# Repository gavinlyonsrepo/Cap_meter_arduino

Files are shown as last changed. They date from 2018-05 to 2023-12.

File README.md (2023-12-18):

    

# Table of contents

  * [Table of contents](#table-of-contents)
  * [Overview](#overview)
  * [Libraries](#libraries)
  * [Parts list](#parts-list)
  * [Software](#software)
	* [Test 1](#test-1)
	* [Test 2](#test-2)
	* [Test 3](#test-3)
  * [Project Schematic](#project-schematic)
  * [See  Also](#see-also)
  
## Overview

* Name : Cap_meter_arduino
* Title : Capacitance meter Arduino based microcontroller.
* Description : Capacitance meter for Arduino, three tests , 
range 18pf to 4F , Push Button input , OLED, serial monitor output and LED(onboard NANO)
* Author: Gavin Lyons

## Libraries

The .ino file( which contains the C++ source code) calls from a number of libraries.

All are standard libraries which can be found on Arduino libray manager.
 
* <Adafruit_SSD1306.h> v 1.1.2 // OLED
* <Button.h> v 1.0.0 // pb https://www.arduinolibraries.info/authors/madleech or https://github.com/madleech/Button

## Parts List

Eagle schematic diagram and image in "docs". 

You will need following parts

> Three pushbuttons
>
> Resistors: Test2( 10K and 220ohm) , Test3(10K, 3.1K, 1.8K)
>
> Arduino NANO micro-controller module (tested on a NANO and UNO)
>
> I2C 0.91" inch 128x32 OLED Display Module SSD1306 Driver IC
>
> Terminals to hold or connect to capacitors during test
>

## Software

The meter measures capacitance it outputs to an OLED and serial monitor.
(The OLED is optional as data via serial monitor on a PC)
Three push buttons start the three tests respectively.

1. Test 1 Range  1 uF to 4F.
2. Test 2 Range 18 pF to 470 uF.
3. Test 3 Range 4.7 nF to 180 uF.

The on-board LED of nano module D13 is used as Status LED.
It Flashes during startup, stays on during "READY to test" state and goes off during "TESTING" state

The OLED displays  brief help message and title screen duirng start-up

Each Arduino capacitance meter relies on a property of resistor capacitor (RC) circuits- the time constant. 
The time constant of an RC circuit is defined as the time it takes for the voltage across the capacitor 
to reach 63.2% of its voltage when fully charged:

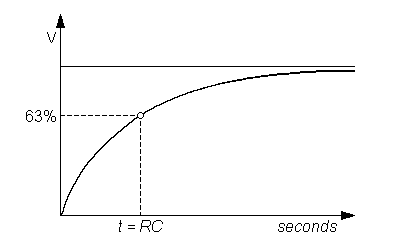
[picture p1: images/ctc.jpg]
ScreenShot cap time constant


Larger capacitors take longer to charge, and therefore will create larger time constants. 
The capacitance in an RC circuit is related to the time constant by the equation:

ScreenShot cap eq constant

The capacitance meter has an RC circuit with known resistor values and an unknown capacitor value. 
The Arduino will measure the voltage at the capacitor and record the time it takes to reach 63.2% of it’s voltage when fully charged (the time constant). 
Since the resistance value is already known, 
we can use the formula above in a program that will calculate the unknown capacitance.

### Test 1

Test 1: Range  1 uF to 4F. 
Uses two digital pins, one analog pin, and two resistors.
One for discharge, one for charge.
Insert a capacitor in range into terminal press button and view result on OLED or serial monitor.
The Capacitor is charged,  We can measure elapsed time until time constant fulfilled using analog pin and we know R 
value. Therefore we solve for C. 
The result gives two values: Capacitance value and time constant to test in mS.
The user can adjust the 10K resistor value in code variable(resistorValue) to match exact value, to improve accuracy

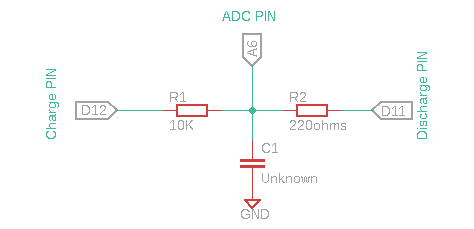
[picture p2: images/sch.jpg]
ScreenShot cap sch


### Test 2

Test 2 : Range 18 pF to 470 uF.

This capacitance test has the greatest range of 3. It also had the highest accuracy with smaller capacitors. 
No resistors are needed and it only uses two analog pins(A2(neg) and A3(positive) from the Arduino.
There is no extra resistor just the internal components of ATmega328 chip.

C1 calibration(optional): 

The internal analog pin capacitor to gnd (C1) varies between 20 and 30pF. unknown capacitor = Cu. The positive pin is set to 5V, the negative to 0V.

VA2 = (VA3 * Cu)/(C1 + Cu)

The value of C1 for any given Arduino board will have to be calibrated using a known cap for Cu,
for full accuracy I set it at 24.48pF in code (CapOne) Found using equation.

C1 = Cu * (VA3-VA2) / VA2

Where  Va2 is ADC value reported by code and VA3 is 5v or 1023.
So for a known capacitor of 103pF giving a ADC value of 801.

C1 = 103pf * (1023-801)/ 801 = 28.48pF.

The user should change this for their system to improve accuracy.
Test a known cap get ADC value and then pop these values into equation above
and put the C1 value into (CapOne) variable in code.

Test equation:

Cu = VA2 * C1 / (VA3 - VA2)

The test displays 3 values 
* Cu,  Capacitance in Farads 
* Time constant for test in mS
* Va2 , ADC measurement from 0 to 1023 where 1023 is 5V 

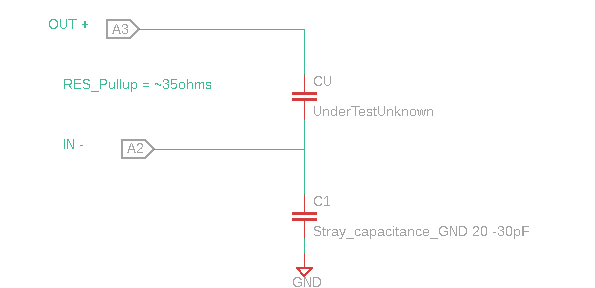
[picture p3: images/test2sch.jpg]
ScreenShot cap sch 2


### Test 3

Test 3 Range 0.0047 uF to 180 uF.

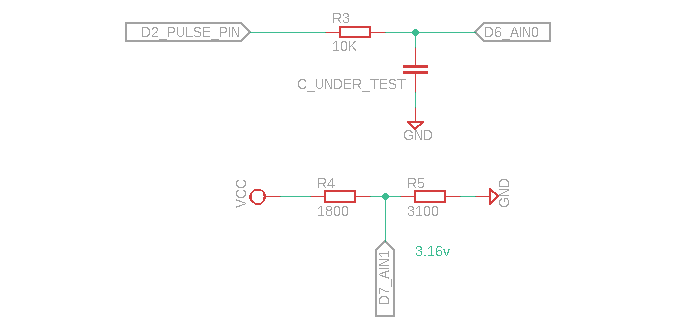
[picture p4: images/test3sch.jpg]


A voltage divider is created to give a reference voltage,

Vout = Vin * (R5 / (R5 + R4)) , 5 * (3100 / (1800 + 3100)) = 3.163.

The objective here is to find the time constant τ (tau) in the equation:

τ = R * C Solved for C: C = τ / R

So we want to charge the capacitor under test with a suitable voltage (eg. 5V from an Arduino output pin) and measure how long it takes to reach 63.2% of that voltage. So we need a reference voltage of 5 * 0.632, namely 3.16V.
The internal analogue comparator is used for this job.:

1. pin 6 PD6 AIN0
2. pin 7 PD7 AIN1
 
We connect the reference voltage to the AIN1 pin (negative reference) and connect our capacitor to the AIN0 pin (positive reference) and then configure an interrupt on the rising edge. A value of 10K for the resistor to give a reasonably slow charge time. The value of ~ 10K is specified in code variable (resistance).
so adjust for your resistor value , I have 9830 ohms. Make sure to pick accurate resistors for voltage divider.

The test returns the Capacitance result and time constant.

## Project Schematic 

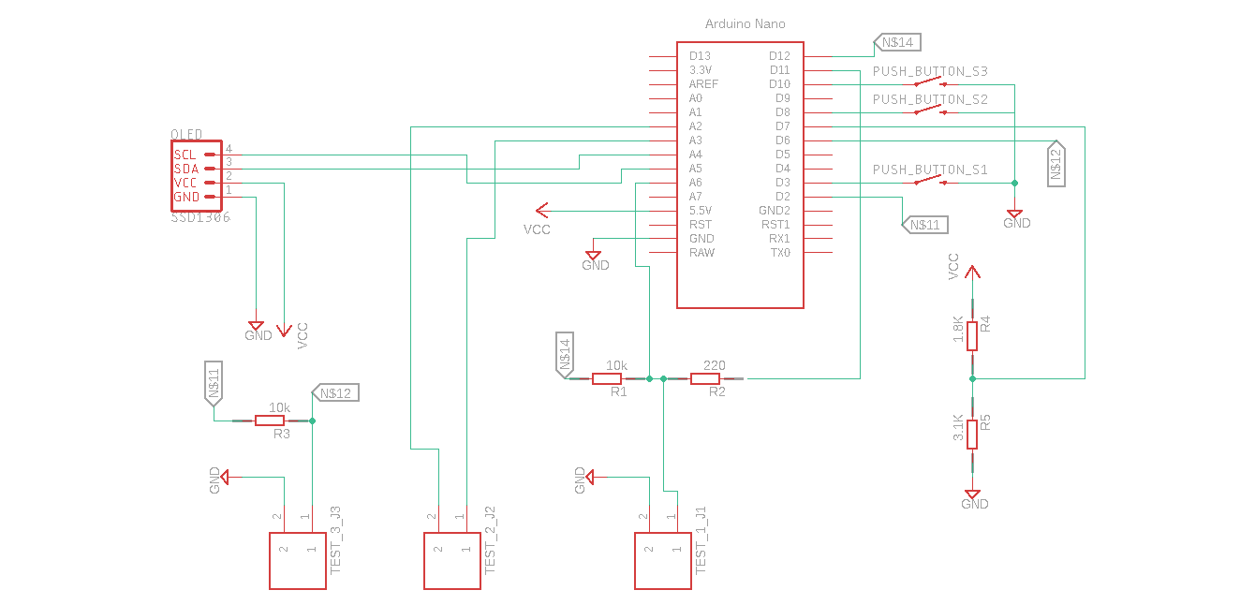
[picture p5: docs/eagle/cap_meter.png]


## See Also
 
* https://www.arduino.cc/en/Tutorial/CapacitanceMeter
* http://www.circuitbasics.com/how-to-make-an-arduino-capacitance-meter/
* http://electronoobs.com/eng_arduino_tut10_1.php
* http://wordpress.codewrite.co.uk/pic/2014/01/21/cap-meter-with-arduino-uno/
* http://www.gammon.com.au/forum/?id=12075

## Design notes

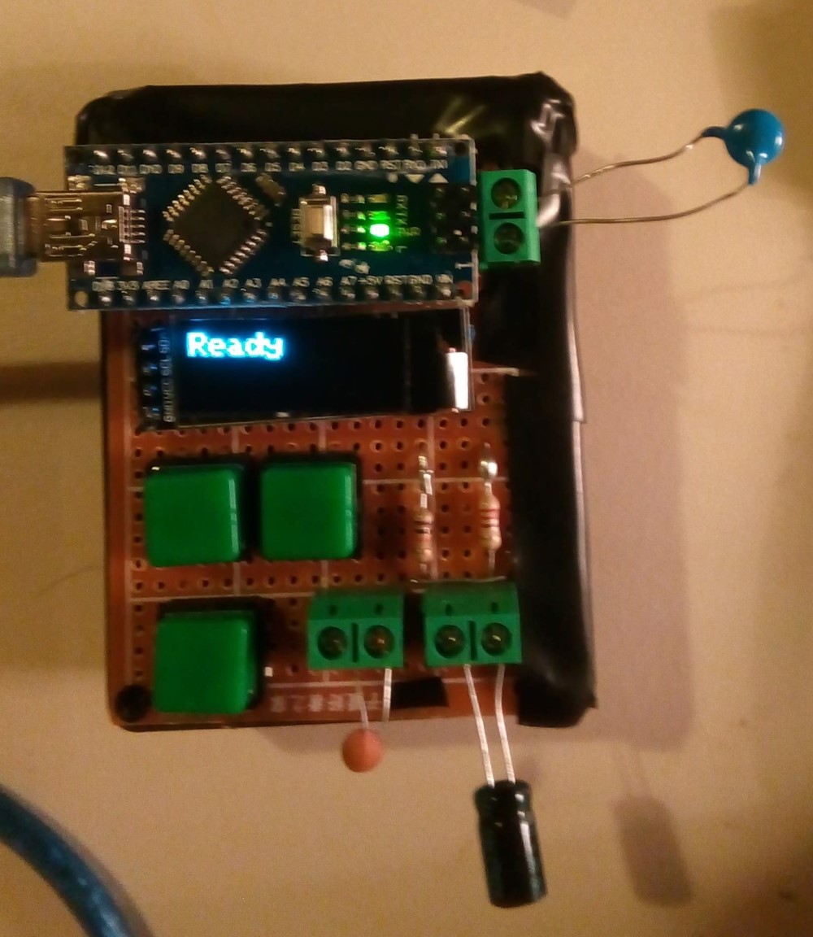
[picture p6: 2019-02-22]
images/project/cap_meter_version_2.1_b.jpg

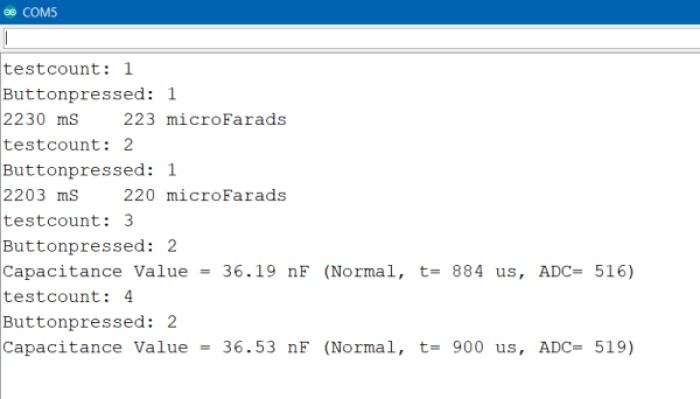
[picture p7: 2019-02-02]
images/Screenshot_serial_mon.jpg

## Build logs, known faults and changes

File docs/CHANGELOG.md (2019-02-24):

# Changelog

* version 1.0-1 May 2018 
	first release

* version 2.0-1 Feb 2019
 	1. Added third test, third button.
	2. Improved and Optimized the information display on the OLED 
	3. Status LED implented using nano onboard
	4. documentation and schematics improvements

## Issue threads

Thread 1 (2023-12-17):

Equation not correct

babristor, 2023-12-17:
the following equation is not correct :
C1 = Cu * (VA3-VA2) / VA3

the correct form is :
C1 = Cu * (VA3-VA2) / VA2

gavinlyonsrepo, 2023-12-18:
Hi

Corrected the typo in  _Test 2 C1 calibration(optional)_ section in the README with commit.

Thank You!

Closed 2023-12-18.

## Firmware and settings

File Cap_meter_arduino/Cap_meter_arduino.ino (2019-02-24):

//******************* HEADER ***********************************
/*
  Name : Cap_meter_ardunio
  Title : Capacitance meter for Ardunio
  Description : Capacitance meter for Ardunio, three tests , range 10pf to 4F , 
  Push Button input , OLED and serial monitor output.
  Author: Gavin Lyons
  URL: https://github.com/gavinlyonsrepo/Cap_meter_arduino
*/

//*************************** LIBRARIES ********************
#include <Wire.h>   //I2C 1.0.0
#include <Adafruit_SSD1306.h> // OLED 1.1.2
#include <Button.h> // push buttons 1.0.0

//*************************** GLOBALS ********************

// LCD data
#define OLED_RESET 4
Adafruit_SSD1306 display(OLED_RESET);


// Pins and vars for test 1 
#define analogPin      6
#define chargePin      12
#define dischargePin   11
#define resistorValue  9988.0F // 10K in theory User adjust


// Pins and vars for test 2
const int OutPin = A3; 
const int InPin = A2;
const float CapOne = 24.48; //user calibrate
const float Res_Pullup = 34.8;
const int MaxADC_Value = 1023;


//Pins and vars for test 3
const byte pulsePin = 2;
const unsigned long resistance = 9830; // (10K in theory) user adjust
volatile boolean triggered;
volatile boolean active;
volatile unsigned long startTime;
volatile unsigned long duration;

//Interupt service rountine
ISR (ANALOG_COMP_vect)
  {
  unsigned long now = micros ();
  if (active)
    {
    duration = now - startTime;
    triggered = true;
    digitalWrite (pulsePin, LOW); 
    }
  }
  
// Buttons and test count
Button btn_test(3);
Button btn_test_two(8);
Button btn_test_three(10);
int test_count = 0;

//*************************** SETUP ************************
void setup() {

   // Status LED
   pinMode(LED_BUILTIN, OUTPUT);
   digitalWrite(LED_BUILTIN, HIGH);  
   delay(80);                    
   digitalWrite(LED_BUILTIN, LOW);
   
  // Setup pins for button enable internal pull-up resistors
  digitalWrite(3, HIGH);
  digitalWrite(8, HIGH);
   digitalWrite(10, HIGH);
  btn_test.begin();
  btn_test_two.begin();
  btn_test_three.begin();

  // Setup pins for test 1
  pinMode(chargePin, OUTPUT);
  digitalWrite(chargePin, LOW);
   
  // Setup pins for test 2
  pinMode(OutPin, OUTPUT);
  pinMode(InPin, OUTPUT);
  
  // setup for test3
  pinMode(pulsePin, OUTPUT);
  digitalWrite(pulsePin, LOW);
  // Set up Analog Comparator
  ADCSRB = 0; // clear ADCSRB registers
  // Analog Comparator Interrupt Flag: Clear Pending Interrupt 
  // Analog Comparator Interrupt: Enabled 
  // Analog Comparator Interrupt Mode: interrupt on the rising edge
  ACSR =  _BV (ACI)
          | _BV (ACIE)
          | _BV (ACIS0) | _BV (ACIS1);
          
  // Setup serial
  Serial.begin(9600);
  //display intial OLED screen
  Display_init();
  Serial.println("------------- CAP Meter Comms UP ------------");
}

//******************* MAIN LOOP *****************
void loop() {
  // *** TEST 1 Range 1 uF to 4F. Left***
  if (btn_test.pressed()) {
    TestButton(1);
    Test_one();
  }
  // *** TEST 2  Range 18 pF to 470 uF. center ***
  if (btn_test_two.pressed()) {
    TestButton(2);
    Test_two();
  }
   // *** Test 3 Range 0.0047 uF to 180 uF. right ***
  if (btn_test_three.pressed()) {
    TestButton(3);
    Test_three();
  }
}

// ********************* FUNCTIONS *************************

//Function to handle test1
void Test_one()
{
  // carry out Test
  unsigned long startTime;
  unsigned long elapsedTime;
  float uF;
  float nF;
  digitalWrite(chargePin, HIGH);
  startTime = millis();
  // 648 is 63.2% of 1024 adc 10 bit = 1024 stop when get to 648
  while (analogRead(analogPin) < 648) {
  }
  elapsedTime = millis() - startTime;

  // Calculate and display value, c = TC/R
  uF = ((float)elapsedTime / resistorValue) * 1000;
  Display_time(elapsedTime);
  if (uF > 1) {
    Serial.print((long)uF);
    Serial.println(" microFarads");
    display.print((long)uF);
    display.print(" uF");
  }
  else {
    nF = uF * 1000.0;
    Serial.print((long)nF);
    Serial.println(" nanoFarads");
    display.print((long)nF);
    display.print(" nF");
    delay(500);
  }
  // Display results OLED
  display.display();

  //discharge
  digitalWrite(chargePin, LOW);
  pinMode(dischargePin, OUTPUT);
  digitalWrite(dischargePin, LOW);
  while (analogRead(analogPin) > 0) {
  }
  pinMode(dischargePin, INPUT);
  delay(4000);
  OLEDready();
}

//Function to carry out Test2
void Test_two()
{
  display.clearDisplay();
  display.setCursor(0, 0);

  pinMode(InPin, INPUT);
  digitalWrite(OutPin, HIGH);
  int val = analogRead(InPin);
  digitalWrite(OutPin, LOW);

  if (val < 1000)
  {
    pinMode(InPin, OUTPUT);
    // Cu = VA2 * C1 / (VA3 - VA2)
    float capacitance = (float)val * CapOne / (float)(MaxADC_Value - val);
    Serial.print(F("Capacitance Value = "));
    Serial.print(capacitance, 3);
    Serial.print(F(" pF ("));
    Serial.print(val);
    Serial.println(F(") "));
    display.print(capacitance, 3);
    display.print(" pF");
  }
  else
  {
    pinMode(InPin, OUTPUT);
    delay(1);
    pinMode(OutPin, INPUT_PULLUP);
    unsigned long u1 = micros();
    unsigned long t;
    int digVal;
    do
    {
      digVal = digitalRead(OutPin);
      unsigned long u2 = micros();
      // condition ? result_if_true : result_if_false
      t = u2 > u1 ? u2 - u1 : u1 - u2;
    } while ((digVal < 1) && (t < 400000L));

    pinMode(OutPin, INPUT);
    val = analogRead(OutPin);

    //discharge
    digitalWrite(InPin, HIGH);
    int dischargeTime = (int)(t / 1000L) * 5;
    delay(dischargeTime);
    pinMode(OutPin, OUTPUT);
    digitalWrite(OutPin, LOW);
    digitalWrite(InPin, LOW);

    float capacitance = -(float)t / Res_Pullup
                        / log(1.0 - (float)val / (float)MaxADC_Value);
    Serial.print(F("Capacitance Value = "));
    if (capacitance > 1000.0)
    {
      Serial.print(capacitance / 1000.0, 2);
      Serial.print(F(" uF"));
      display.print(capacitance / 1000.0, 2);
      display.print(" uF");
    }
    else
    {
      Serial.print(capacitance, 2);
      Serial.print(F(" nF"));
      display.print(capacitance, 2);
      display.print(" nF");
    }

    Serial.print(F(" ("));
    // condition ? result_if_true : result_if_false
    Serial.print(digVal == 1 ? F("Normal") : F("HighVal"));
    Serial.print(F(", t= "));
    Serial.print(t);
    Serial.print(F(" us, ADC= "));
    Serial.print(val);
    Serial.println(F(")"));
    display.setCursor(0, 12);
    display.print("t = ");
    display.print(t);
    display.print(" uS");
    display.setCursor(0, 22);
    display.print("ADC = ");
    display.print(val);   
  }
  while (millis() % 1000 != 0);
  display.display();
  delay(4000);
  OLEDready();
}

//Function to carry out Test3
void Test_three(void)
  
  {
  boolean exitloop = false;
  while(exitloop != true)
  {
    if (!active)
      {
      active = true;
      triggered = false;
      digitalWrite (pulsePin, HIGH); 
      startTime = micros ();  
      }
  
    if (active && triggered)
      {
      active = false;
      Serial.print ("Capacitance = ");
      Serial.print (duration * 1000 / resistance);
      Serial.println (" nF");
      Serial.print ("duration = ");
      Serial.println(duration);
      Serial.println (" uS");
      triggered = false;
      //OLED
      display.clearDisplay();
      display.setCursor(0, 10);
      display.setTextSize(1);
      display.print((duration * 1000 / resistance));
      display.print(" nF");
      display.setCursor(0, 25);
      display.print("t = ");
      display.print(duration);
      display.print(" uS");
      
      display.display();
      delay (4000);
      OLEDready();
      exitloop = true; //exit when test finished. 
      }
  }
}

// Function to handle button press start display to OLED and serial monitor
void TestButton(int which_button)
{
  digitalWrite(LED_BUILTIN, LOW);
  test_count ++;
  
  Serial.print("testcount: ");
  Serial.println(test_count);
  Serial.print("Buttonpressed: ");
  Serial.println(which_button);
  Serial.println ("Testing");
  
  display.clearDisplay();
  display.setCursor(0, 0);
  display.setTextSize(1);
  display.setTextColor(WHITE);
  display.print("Testing: ");
  display.print(which_button);
  display.setCursor(0, 15);
  display.print("Count: ");
  display.print(test_count);
  display.display();
}

//Function to Display elasped time to OLED and Serial Monitor called from test1 function
void Display_time(unsigned long elaspedTime)
{
  Serial.print(elaspedTime);
  Serial.print(" mS    ");
  
  display.clearDisplay();
  display.setCursor(0, 25);
  display.print(elaspedTime);
  display.print(" mS");
  display.setCursor(0, 5);
}

// Function to display init screen in setup
void Display_init()
{
  display.begin(SSD1306_SWITCHCAPVCC, 0x3C);
  display.clearDisplay();
  
  display.setCursor(0, 0);
  display.setTextSize(2);
  display.setTextColor(WHITE);
  display.print("Cap Meter");
  display.setCursor(0, 15);
  display.print("Ver 2.1");
  display.display();
  delay(1500); 
  display.clearDisplay();
  
  display.setTextSize(1);
  
  display.setCursor(0, 0);
  display.print("Test 1 right");
  display.setCursor(0, 15);
  display.print("Range 1uF - 4F");
  display.display();
  delay(1500);
  display.clearDisplay();
  
  display.setCursor(0, 0);
  display.print("Test 2 left");
  display.setCursor(0, 15);
  display.print("Range 18pF - 470uF");
  display.display();
  delay(1500);
  display.clearDisplay();

  display.setCursor(0, 0);
  display.print("Test 3 top");
  display.setCursor(0, 15);
  display.print("Range 4.7nF - 180uF");
  display.display();
  delay(1500);
  
  OLEDready();
  
}

//Function to display ready message and Status LED
void OLEDready()
{ 
  display.clearDisplay();
  display.setTextSize(2);
  display.setCursor(0, 0);
  display.print("Ready");
  display.display();
  digitalWrite(LED_BUILTIN, HIGH);
}

//******************* EOF *****************

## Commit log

2018-05-08 version 1.0-1
    [LCR_meter.fzz]
2018-05-14 re-org files in repo
    [LCR_meter.fzz]
2018-10-31 version 1.1-2
    [LCR_meter.fzz]
2019-01-30 replacing schemtic , Fritzing with Eagle
    [LCR_meter.fzz, cap_meter.sch]
2019-02-02 version 2.0
    [cap_meter.sch]
2019-02-22 version 2.1-2
    [cap_meter.sch]
2019-02-24 schemtic update
    [cap_meter.sch]
